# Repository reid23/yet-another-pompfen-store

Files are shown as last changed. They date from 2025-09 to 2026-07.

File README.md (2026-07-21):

# yet-another-pompfen-store

Pompfen engineered for robustness, maintainability, accessibility, and
performance.

> [!IMPORTANT] 
> This content is licensed under [AGPL v3](LICENSE)[^1] because I want
> to encourage sharing within the community.  I hope that I'm never
> going to have to argue about the details with anyone about this. The
> main things I want are:
> 
>  - If you use this in your own work (directly, or even just
>    borrowing some design features), you must also release your work
>    under AGPL v3.  
>  - If you designed your parts in a different cad software, please
>    share the designs in the native format or STEP. I don't think
>    mesh files count as "source".
>  - While not required by the license, attribution would be nice!  
> 
> I am uploading this work for free use (in all senses) because I want
> to see Jugger continue to grow and the equipment to improve. Please
> carry that spirit forward.

## TLDR

- See [order.md](docs/order.md) for information on ordering and poke
  around the configuration options & prices at
  [reid.xz.ax/yaps](reid.xz.ax/yaps) (looks better on a computer than
  on mobile).
- See [code.md](docs/code.md) for information on this codebase and how
  to work with it.
- See [build-your-own.md](docs/build-your-own.md) for how to build
  these yourself!

## Features

Really this section should be after the motivation/project goals bit,
but I know everyone just wants to read the cool feature list first. So
here it is:

- Modularity: the core, blade, buffer, and cover are all separate
  parts which can be repaired or replaced independently.
  - The buffer is a small piece of foam at the back of all blades
    except q-tip. It is squishy, protecting the blade-core interface
    from large forces when a chain wraps and tugs.
  - Removing or installing a blade takes less than a minute.
- Lightweight: these sticks are very light. It's not the bleeding edge
  of lightweight performance, but it's pretty damn good. As a general
  reference, the Q-tip is <250g.
- No more spacers! The foam has a hole inside the same size as the
  core.
- Nylon ripstop blade covers: instead of clear tape, we use nylon
  ripstop fabric. Tears propagate way less, it's lighter, it's
  replaceable, it (imo) looks better, it can be removed and washed,
  and it can be made from a variety of colors for customization.
- Long and Staff blades are interchangeable!
- Choose between a wide (3") or narrow (2.25") staff guard
- EPP reinforcement at the ends of the blades gives Qtip players more
  control and protects the edge of the foam on all weapons.

## OKRs

Here's what this project is trying to do.

When developing these pompfen, I was focused on the following
objectives:
- be inarguably rule compliant
- be safe in normal use and in failure
- be maintainable
- be accessible
- be lightweight
- look good

In order to accomplish this, I developed the following key results:
- The design and manufacturing process must be standardized and
  repeatable to ensure that my goals can be satisfied not just by one
  pompf, but many.
- The design must be modular so that individual components can be
  replaced instead of tearing down the whole pompf every time a small
  fix needs to be made.
- The pompf should withstand many different environments (heat, sun,
  rain, snow, etc).
- The pompf should last through regular usage for at least a year with
  less than $1 and 20 minutes of maintainence over the course of that
  year.
- All safety-critical failures must be visible and ideally not occur
  suddenly (I say 'ideally' because there's only so much you can do if
  the core snaps in half).
- The results of this effort should be made public and free (as in
  free beer *and* as in free speech) for the wider Jugger community to
  use and build upon.
- The pompf should be sold at or below typical US market rates.

Within the bounds of these constraints, I seek to optimize for
weight[^2] and aesthetics.

[^1]: I am aware that this is not very well suited for hardware
    projects (I'm not sure if there even is a good license for
    OpenSCAD projects). But it captures the spirit of what I'm trying
    to do, and I hope that the details never become relevant
    anyway. Please be nice and share your work.

[^2]: technically by weight I mean some strange cost function of the
    inertia tensor that captures what makes a weapon maneuverable. I
    do assume that this function is positive definite though (ie, I do
    not consider the "I like heavy weapons because they make it easier
    to chainbreak/push through an opponent's parry/build
    momentum/etc.).

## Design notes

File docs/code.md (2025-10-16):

## Code Documentation

This document gives an overview of how this design was implemented.

### Setup

There shouldn't be much setup. Just clone the repo. If you don't have [BOSL2](https://github.com/BelfrySCAD/BOSL2) installed, you can just `git submodule init` and `git submodule update` to get it in the repo directory.

You may also need to `chmod +x buildall` before you can run the build script. It references `/usr/bin/python`, so if that doesn't exist, make a symlink (or change the interpreter in `buildall` or run it with python or whatever you'd like)

### Build System

I made a silly little custom build system, since openscad is funny and I couldn't find something that fits my needs.
You'll see comments above modules like this:

```openscad
// @build tip_thread_m_nodfm.stl include_dfm=false
// @build tip_thread_m.stl include_dfm=true
module tip_thread_m(
   // ...,
   include_dfm=true){
    // ...
}
```

This tells the build system to build two stls from this module: one with the parameter `include_dfm` set to `true`, and the other `false`.

To build the .stl files, run the build script:

```bash
./buildall
```

There are a variety of command line arguments. You can see the docs with `./buildall --help`.

This exports all files to the build folder. It also runs the CAM script, which generates some gcode for cutting the EPP. This is not well documented since it was just a one-off I made for myself and my specific setup. If you want to do a similar thing, you should just write your own gcode. It's not hard, and you'll be able to debug it much easier.

If you do want to use mine, you can see the docs like this:
```bash
python epp_cam.py --help
```

Any unknown arguments to `./buildall` are passed to `epp_cam.py`, so you can set the CAM parameters when using the `./buildall` script.

### Assemblies

`assemblies.scad` contains all TLAs (**T**op-**L**evel **A**ssemblies). This is not as helpful as it should be; you still have to go in and highlight or hide things to actually see what's going on, because openscad doesn't have a great way to prevent merging of touching parts.
It maybe helpful to make a section view:

```openscad
difference(){
    long_tla();
    cube(10000, anchor=RIGHT);
}
```

### Parameters

All values are in millimeters. If you have a measurement in inches, there's a convenient variable `INCH` which is defined as `25.4`; please use `INCH` instead of the number to avoid magic numbers.

`params.scad` contains all system-wide parameters. Other parameters fall into two categories:
 - **local parameters** are arguments to modules. They only impact the part generated by that module (not its children).
 - **shared parameters** are variables starting with a `$`, which openscad shares with children. This helps parts that need to fit together share the same parameters. Defaults are defined at the top of the files, and new values can be passed in as keyword arguments to modules.

At some point in the future I hope to integrate this with Customizer, but that's not high on my priority list right now.

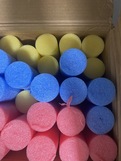
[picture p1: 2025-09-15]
assets/noodle_colors_resized.jpg

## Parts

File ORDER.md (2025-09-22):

## How to Order

You can order a product by sending me a list of SKUs and quantities. Below is the full SKU map.
- Postfix your resulting SKU with the version. This ensures that I'll make compatible components. The current release is always available at [github.com/reid23/yet-another-pompfen-store/releases/latest](https://github.com/reid23/yet-another-pompfen-store/releases/latest).
  - ex: if you order a wide shortstaff guard with cover for version 0.2.1, your final SKU would be `F-GU-SS-COV-v0.2.1`.
- `XXXX` is the cover & foam color options, which are listed [below](#cover--color-options).
- `[SH|LO|QT|ST|SS]` are weapon types. They correspond to short, long, q-tip, staff, and shortstaff, respectively.
- All staff guards will be opaque black for now. If you really want something different let me know, but I don't see a ton of demand for this.

> [!NOTE]
> **UPDATE** I made a little website to help configure this! Go to [reid.xz.ax/yaps](https://reid.xz.ax/yaps) to configure everything and get the price & SKU. The mobile UI is not wonderful, but I have neither the time nor desire to fix it.
> **please still read this file**, since it contains important information and suggestions.

### 1. Full Weapon (`W`)

`CP` ("core provided") is if you'll give me a core or ordered one in the core order and want me to use it. `NC` ("no core provided") is if you want me to provide the core.  

`PO` means "pommel"; `NP` means "no pommel". choose the latter if you want to make your own. You'll need to cut the end of the core to length based on how thick your pommel will be.  

The format is `W-[CP|NC]-[SH|LO|QT|ST[W|N]|SS[W|N]]-[PO|NP]-XXXX`:
- Short: `W-[CP|NC]-SH-[PO|NP]-XXXX`
- Long: `W-[CP|NC]-LO-[PO|NP]-XXXX`
- Q-tip: `W-[CP|NC]-QT-XXXX`
- staff: `W-[CP|NC]-[ST|SS]-[W|N]-[PO|NP]-XXXX`
  - `ST` is full staff, `SS` is shortstaff
  - `W` is wide guard (3"), `N` is narrow guard (2.25")

### 2. Foam (`F`)

This is where you can get blades and guards separately if you want.

Use `COV` if you want a cover or `NC` if you don't (ie, if you're replacing an old bit of foam but the old cover is still fine).

**Important**: if you are reusing a cover, make sure the foam color you request is the same as the one you originally had! Each color of noodle has a slightly different diameter, so the covers are noodle-color-specific.

- Long/Staff (`F-LO-[COV|NC]-XXXX`)
- Short (`F-SH-[COV|NC]-XXXX`)
- Q (`F-QT-[COV|NC]-XXXX`) (only a single blade!)
- Staff Guard (`F-GU-[ST|SS][W|N]-[COV|NC]`) (does not include grip!)
  - `ST` for full staff, `SS` for shortstaff
  - `W` for wide (3"), `N` for narrow (2.25")

### 3. Core (`C`)

Complete cores are cut to length for a weapon and contain all hardware needed for that weapon preinstalled.

The "raw cores" are just what you get from the core order, but immediately! If you need a core now, you can get one, but otherwise i'd recommend waiting for the next core order to get a lower price. These have the 'Reid maintains inventory, fronts cost, and stores cores in his house' fee added.

- Complete (`C-CMP-[SH|LO|QT|ST|SS]`)
- Raw (`C-RAW-[LO|2SH|QT]`)
  - `LO` is 1.35m, for longsword
  - `2SH` is 1.6m, for two shorts.
  - `QT` is 1.9m, for a Q, staff, or shortstaff.

### 4. Parts (`P`)
- Pommel (`P-PO`)
- Blade Hardware Kit (`P-BHK`)
- Staff Guard Hardware (`P-SGH`)
- Staff Grip (`P-SGR-[W|N]`)
  - `W` for wide (3") and `N` for narrow (2.25")

## Pricing

Full weapon costs are the sum of the complete core, foam assemblies, pommel, and grip costs. If you provide a core, there is no core cost, but the appropriate mouting hardware kit costs are added.

Foam Assemblies (Blades/Guards):
- Short: $30 ($21 without cover)
- Long: $40 ($29 without cover)
- Qtip: $28/side ($19 without cover)
- Staff/Shortstaff Guard: $20 ($13 without cover)

Complete Cores (with hardware):
- Short: $21
- Long: $31
- Staff & Shortstaff: $43.5
- Qtip: $44

Raw Cores:
- 1.35m (long): $30.00
- 1.6m (2 shorts): $38.40
- 1.9m (q, staff): $42.50

Mounting hardware kits: 
- $2 per blade
- $1.5 per staff guard

Pommel: $2
Staff grip: $5

A few comments:
- If you have an existing core, I would highly recommend getting a hardware kit and installing it yourself instead of buying a new core. It will cut cost significantly, and the process is very easy. You need superglue, a tape measure, a lighter or heat gun, and some tape (preferrably athletic tape, but any should do).
- If you're replacing an old blade, if the cover is still in good shape, buy a blade without the cover! It's much less labor for me and thus much cheaper for you.
- No tape is applied to the handles by default. If you want it, you need to add it yourself. Everyone has a different opinion on how this should be done, so I'm just going to leave it up to you.

## Cover & Color Options

There are two cover material options:

| Property | 1.1oz Silnylon Ripstop | 1.0 oz MONOLITE Ripstop Nylon Mesh |
| :--- | :--- | :--- |
| **General** | | |
| Waterproof | Yes | No |
| Opaque | dark colors yes, light are more translucent  | No |
| **Dimensions** | | |
| Weight | 1.1 oz | 1.0 oz |
| Thickness | 2.4 thou | 3.9 thou |
| Thread Count (warp/weft) | 200 / 180 per inch | 178 / 178 per inch |
| **Strength (warp/weft)** | | |
| Tear Strength | 13.4 / 10.1 lbf | 1.6 / 3.0 lbf |
| Tensile Strength | 18.9 / 16.2 lbf | 22.3 / 24.8 lbf |

You can see a visual comparison of the two [here](https://www.youtube.com/watch?v=gX634O65S6A). Ignore the first fabric. the second looks like the opaque silnylon but is much weaker because it lacks the silicone coating. the third fabric is the mesh.

There's also Silpoly which looks to have the right specs and has some more colors, but I have not experimented with it yet, so I won't claim that it works well. You can take a look yourself though: https://ripstopbytheroll.com/products/1-1-oz-silpoly

To be entirely honest, the technical details are mostly irrelevant. Both options are similarly strong and robust, and weight basically the same. If anything, the mesh is likely a tiny bit tougher, but rips propagate slightly easier.

I maintain inventory with proper safety stock of black for both of these fabrics. If you want a different color, there will be a $5 additional charge for each new color you'd like (ie, if you order five bright pink pompf it'll still only be $5 extra).

If you would like me to make a cover from a custom fabric, I can do that! Just contact me directly.

The noodle underneath the cover comes in three colors: red, blue, and yellow. They look like this: 

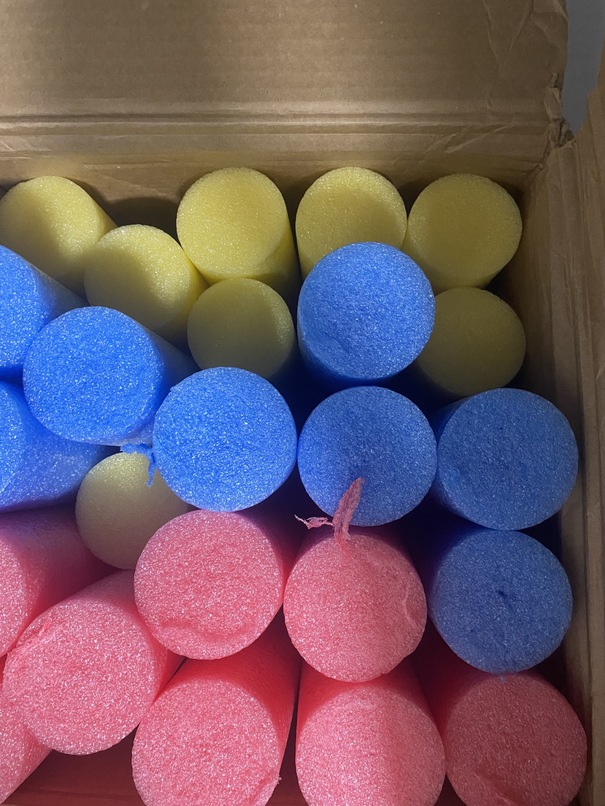
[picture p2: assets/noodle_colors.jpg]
noodle colors


If you go with the opaque Silnylon cover (ie, one of the darker colors of silnylon), you'll basically never see this. At most, it's a tiny accent at the edge of the blade (on everything except qtip, where it isn't visible at all). If you go with the mesh, you can see the color through the cover.

Please let me know what color noodle you'd like by appending an `R`, `B`, `Y`, (red, blue, yellow) or `X` (no preference) to the end of the three-letter ripstop color SKU (see below) you tell me.

The color options in fabrics I've tested are below. Please tell me the SKU of the one you want.

| in stock? | extra fee? | SKU | human readable name  | image |
| --- | --- | --- | --- | ----- |
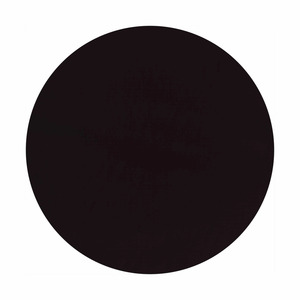
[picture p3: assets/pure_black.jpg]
pure black
| yes | NO  | PBR | pure black |  |
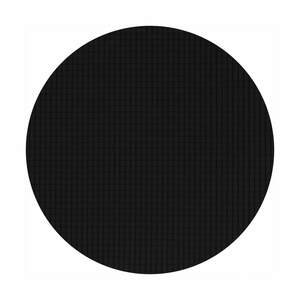
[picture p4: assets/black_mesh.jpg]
black mesh
| yes | NO  | PBM | pure black mesh |  |
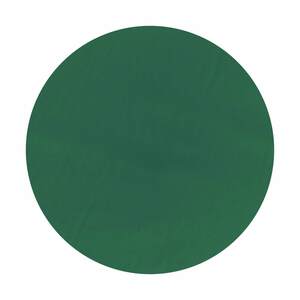
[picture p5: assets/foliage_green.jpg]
foliage green
| yes | yes | FGR | foliage green |  |
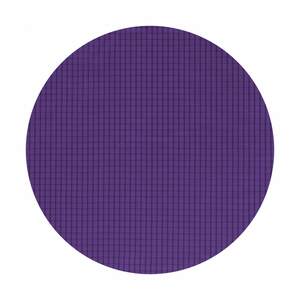
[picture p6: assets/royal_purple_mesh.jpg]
royal purple mesh
| yes | yes | RPM | royal purple mesh |  |
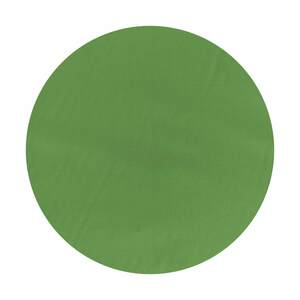
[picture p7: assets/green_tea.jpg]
green tea
| yes | yes | GTR | green tea |  |
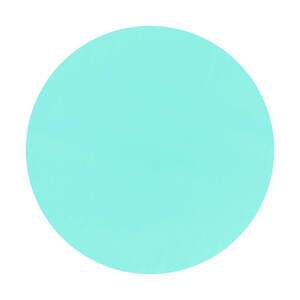
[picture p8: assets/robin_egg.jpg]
robin egg
| yes | yes | RER | robin egg blue |  |
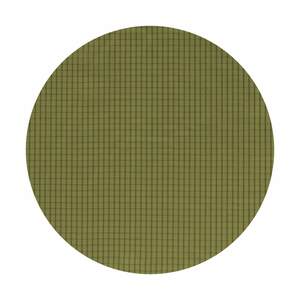
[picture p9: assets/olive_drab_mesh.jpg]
olive drab mesh
| yes | yes | ODM | olive drab mesh |  |
| NO  | yes | RPR | royal purple | royal purple |
| yes | yes | DOR | dark olive | dark olive |
| yes | yes | RTR | real teal | real teal |
| yes | yes | ORM | blaze orange mesh | blaze orange mesh |
| yes | yes | BOR | blaze orange | blaze orange |
| yes | yes | HPR | hot pink | hot pink |
| yes | yes | ODR | olive drab | olive drab |
| yes | yes | PWR | plain white | plain white |
| NO  | yes | CGR | charcoal gray | charcoal gray |
| yes | yes | DOM | dark olive mesh | dark olive mesh |
| yes | yes | MBM | moroccan blue mesh | moroccan blue mesh |
| yes | yes | BOM | burnt orange mesh | burnt orange mesh |
| yes | yes | HGM | hunter green mesh | hunter green mesh |
| yes | yes | WMR | white mesh | white mesh |
| yes | yes | CBR | coyote brown | coyote brown |
| yes | yes | BYR | blaze yellow | blaze yellow |
| yes | yes | CGM | charcoal gray mesh | charcoal gray mesh |

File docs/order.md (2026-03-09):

## How to Order

You can order a product by sending me a list of SKUs and
quantities. Below is the full SKU map.
- Postfix your resulting SKU with the version. This ensures that I'll
  make compatible components. The current release is always available
  at
  [github.com/reid23/yet-another-pompfen-store/releases/latest](https://github.com/reid23/yet-another-pompfen-store/releases/latest).
  - ex: if you order a wide shortstaff guard with cover for version
    0.2.1, your final SKU would be `F-GU-SS-COV-v0.2.1`.
- `XXXX` is the cover & foam color options, which are listed
  [below](#cover--color-options).
- `[SH|LO|QT|ST|SS]` are weapon types. They correspond to short, long,
  q-tip, staff, and shortstaff, respectively.
- All staff guards will be opaque black for now. If you really want
  something different let me know, but I don't see a ton of demand for
  this.

> [!NOTE]
> 
> **UPDATE:** I made a little website to help configure this! Go to
> [reid.xz.ax/yaps](https://reid.xz.ax/yaps) to configure everything
> and get the price & SKU. The mobile UI is not wonderful, but I have
> neither the time nor desire to fix it.  **please still read this
> file**, since it contains important information and suggestions.

### 1. Full Weapon (`W`)

`CP` ("core provided") is if you'll give me a core or ordered one in
the core order and want me to use it. `NC` ("no core provided") is if
you want me to provide the core.  

`PO` means "pommel"; `NP` means "no pommel". choose the latter if you
want to make your own. You'll need to cut the end of the core to
length based on how thick your pommel will be.  

The format is `W-[CP|NC]-[SH|LO|QT|ST[W|N]|SS[W|N]]-[PO|NP]-XXXX`:
- Short: `W-[CP|NC]-SH-[PO|NP]-XXXX`
- Long: `W-[CP|NC]-LO-[PO|NP]-XXXX`
- Q-tip: `W-[CP|NC]-QT-XXXX`
- staff: `W-[CP|NC]-[ST|SS]-[W|N]-[PO|NP]-XXXX`
  - `ST` is full staff, `SS` is shortstaff
  - `W` is wide guard (3"), `N` is narrow guard (2.25")

### 2. Foam (`F`)

This is where you can get blades and guards separately if you want.

Use `COV` if you want a cover or `NC` if you don't (ie, if you're
replacing an old bit of foam but the old cover is still fine).

**Important**: if you are reusing a cover, make sure the foam color
you request is the same as the one you originally had! Each color of
noodle has a slightly different diameter, so the covers are
noodle-color-specific.

- Long/Staff (`F-LO-[COV|NC]-XXXX`)
- Short (`F-SH-[COV|NC]-XXXX`)
- Q (`F-QT-[COV|NC]-XXXX`) (only a single blade!)
- Staff Guard (`F-GU-[ST|SS][W|N]-[COV|NC]`) (does not include grip!)
  - `ST` for full staff, `SS` for shortstaff
  - `W` for wide (3"), `N` for narrow (2.25")

### 3. Core (`C`)

Complete cores are cut to length for a weapon and contain all hardware
needed for that weapon preinstalled.

The "raw cores" are just what you get from the core order, but
immediately! If you need a core now, you can get one, but otherwise
i'd recommend waiting for the next core order to get a lower
price. These have the 'Reid maintains inventory, fronts cost, and
stores cores in his house' fee added.

- Complete (`C-CMP-[SH|LO|QT|ST|SS]`)
- Raw (`C-RAW-[LO|2SH|QT]`)
  - `LO` is 1.35m, for longsword
  - `2SH` is 1.6m, for two shorts.
  - `QT` is 1.9m, for a Q, staff, or shortstaff.

### 4. Parts (`P`)
- Pommel (`P-PO`)
- Blade Hardware Kit (`P-BHK`)
- Staff Guard Hardware (`P-SGH`)
- Staff Grip (`P-SGR-[W|N]`)
  - `W` for wide (3") and `N` for narrow (2.25")

## Pricing

Full weapon costs are the sum of the complete core, foam assemblies,
pommel, and grip costs. If you provide a core, there is no core cost,
but the appropriate mouting hardware kit costs are added.

Foam Assemblies (Blades/Guards):
- Short: $30 ($21 without cover)
- Long: $40 ($29 without cover)
- Qtip: $28/side ($19 without cover)
- Staff/Shortstaff Guard: $20 ($13 without cover)

Complete Cores (with hardware):
- Short: $21
- Long: $31
- Staff & Shortstaff: $43.5
- Qtip: $44

Raw Cores:
- 1.35m (long): $30.00
- 1.6m (2 shorts): $38.40
- 1.9m (q, staff): $42.50

Mounting hardware kits: 
- $2 per blade
- $1.5 per staff guard

Pommel: $2
Staff grip: $5

A few comments:
- If you have an existing core, I would highly recommend getting a
  hardware kit and installing it yourself instead of buying a new
  core. It will cut cost significantly, and the process is very
  easy. You need superglue, a tape measure, a lighter or heat gun, and
  some tape (preferrably athletic tape, but any should do).
- If you're replacing an old blade, if the cover is still in good
  shape, buy a blade without the cover! It's much less labor for me
  and thus much cheaper for you.
- No tape is applied to the handles by default. If you want it, you
  need to add it yourself. Everyone has a different opinion on how
  this should be done, so I'm just going to leave it up to you.

## Cover & Color Options

> [!NOTE]
> 
> I have discontinued the non-mesh cover options, as they would creep
> (stretch) over time and become loose.

I maintain inventory with proper safety stock of black fabric. If you
want a different color, there will be a $5 additional charge (since I
have to order new fabric, pay shipping, and make the covers custom to
order instead of making a bunch ahead of time).

If you would like me to make a cover from a custom fabric, I can do
that! Just contact me directly and we can work something out. I would
recommend that you still keep the ripstop mesh unerneath, since it is
very strong and can serve as the protective layer so you have more
freedom to choose an external decorative layer without worrying about
structural integrity.

The noodle underneath the cover comes in three colors: red, blue, and
yellow. They look like this:

noodle colors

Please let me know what color noodle you'd like by appending an `R`,
`B`, `Y`, (red, blue, yellow) or `X` (no preference) to the end of the
three-letter ripstop color SKU (see below) you tell me.

The color options in fabrics I've tested are below. Please tell me the
SKU of the one you want.

| in stock? | extra fee? | SKU | human readable name  | image |
| --- | --- | --- | --- | ----- |
| yes | NO  | PBM | pure black mesh | black mesh |
| yes | yes | RPM | royal purple mesh | royal purple mesh |
| yes | yes | ODM | olive drab mesh | olive drab mesh |
| yes | yes | ORM | blaze orange mesh | blaze orange mesh |
| yes | yes | DOM | dark olive mesh | dark olive mesh |
| yes | yes | MBM | moroccan blue mesh | moroccan blue mesh |
| yes | yes | BOM | burnt orange mesh | burnt orange mesh |
| yes | yes | HGM | hunter green mesh | hunter green mesh |
| yes | yes | WMR | white mesh | white mesh |
| yes | yes | CGM | charcoal gray mesh | charcoal gray mesh |

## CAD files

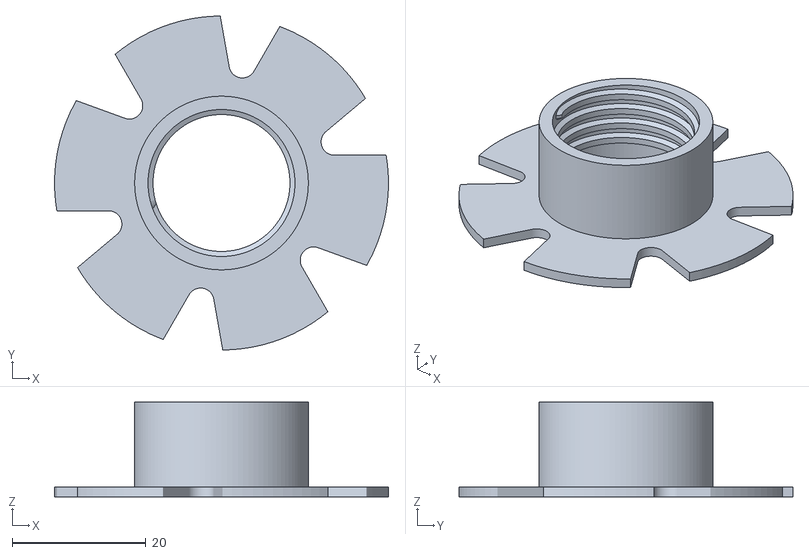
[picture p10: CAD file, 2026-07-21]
build/components/guard_thread_f.stl
50.0 x 50.0 x 14.2

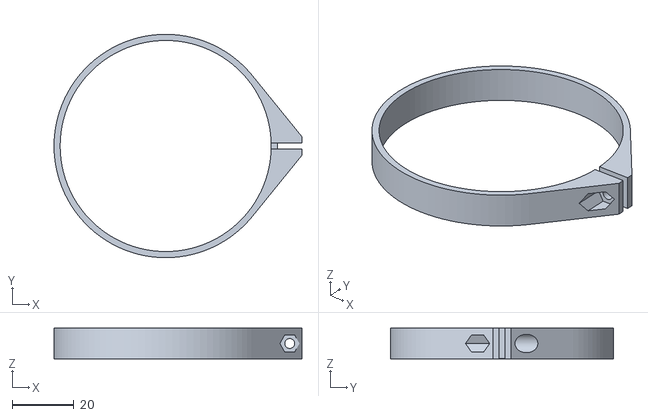
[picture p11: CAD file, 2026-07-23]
build/extras/blade_epp_cutter_outer_clamp.stl
80.6 x 72.6 x 10.0

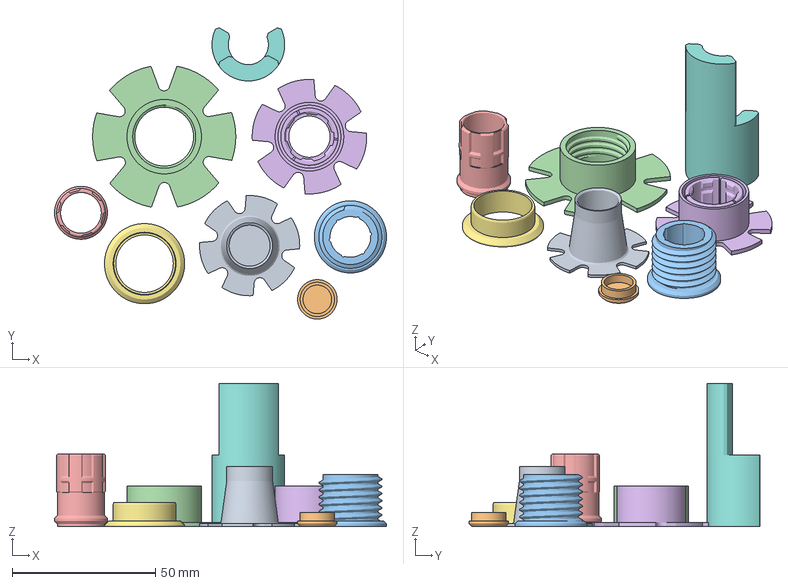
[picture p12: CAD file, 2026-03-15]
slice/pp_all.3mf
115.9 x 101.7 x 50.0 mm
tip_flange.stl
tip_cap.stl
guard_thread_m.stl
guard_thread_f.stl
blade_m.stl
blade_f.stl
collet.stl
staff_guard_spacer.stl

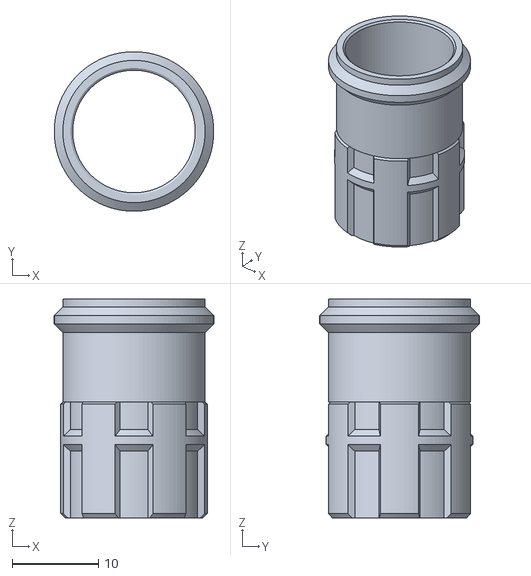
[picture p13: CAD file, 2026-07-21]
build/components/blade_m.stl
18.5 x 18.5 x 25.4

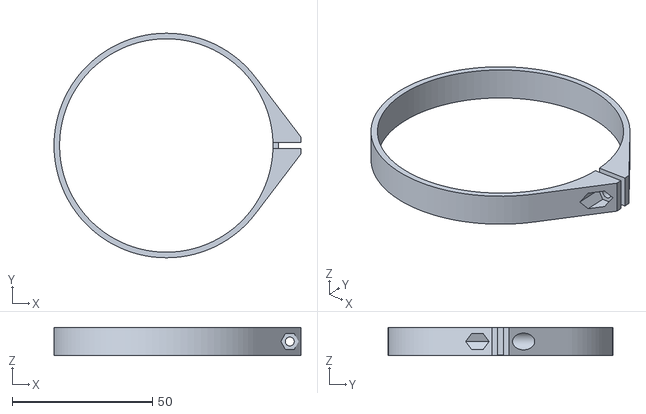
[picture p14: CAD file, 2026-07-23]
build/extras/guard_epp_cutter_outer_clamp.stl
88.2 x 80.2 x 10.0

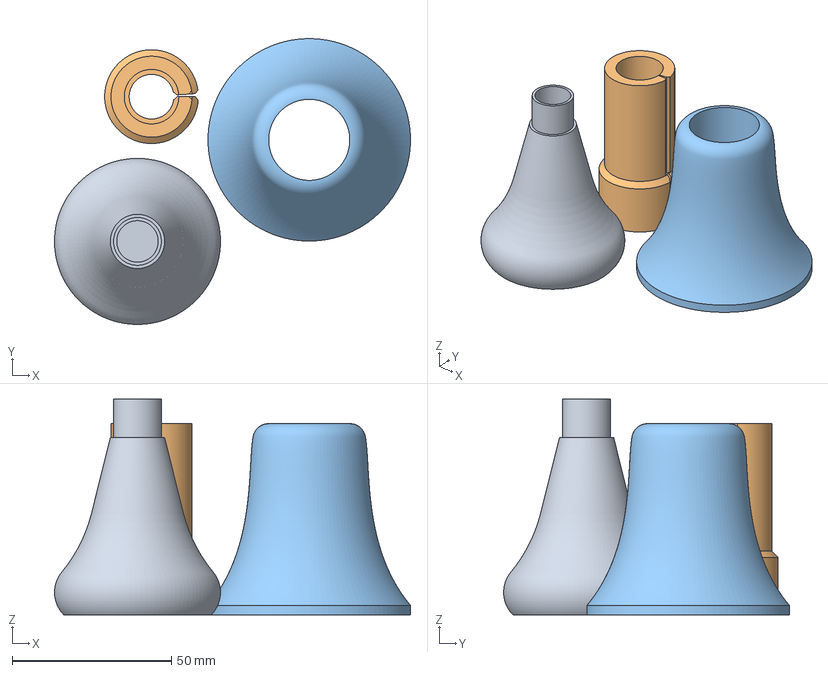
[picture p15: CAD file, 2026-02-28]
slice/flexibles.3mf
111.6 x 89.6 x 67.7 mm
pommel.stl
staff_spacer.stl
staff_grip.stl

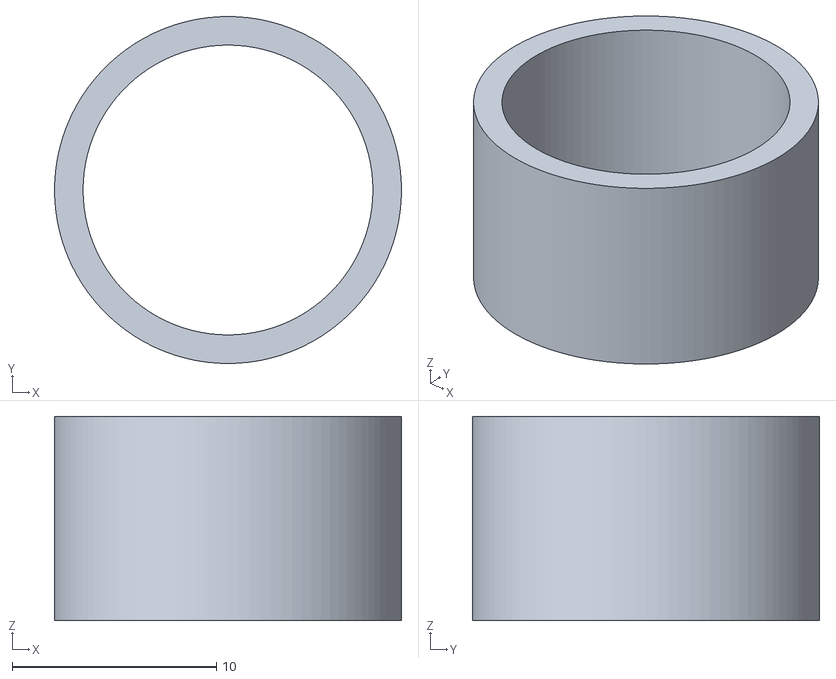
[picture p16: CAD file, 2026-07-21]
build/components/staff_grip_collar.stl
17.0 x 17.0 x 10.0

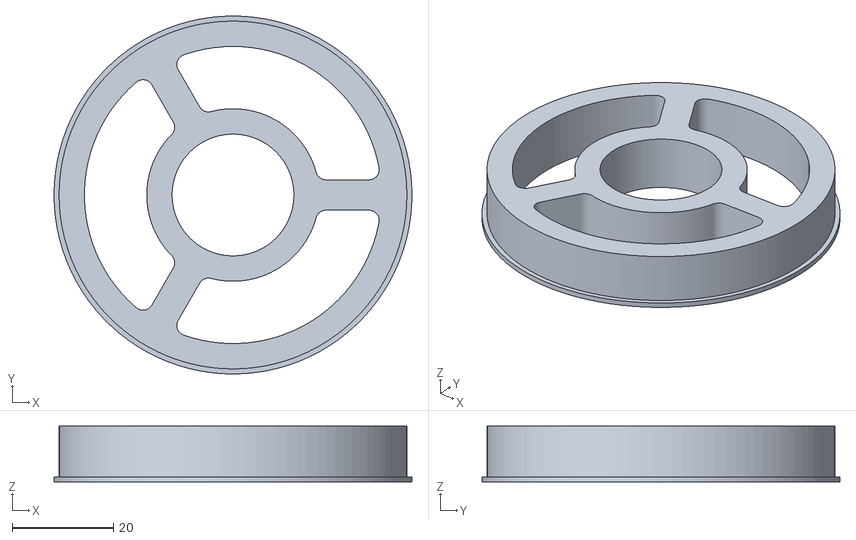
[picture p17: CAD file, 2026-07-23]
build/extras/blade_handside_epp_cutter.stl
70.6 x 70.6 x 11.0

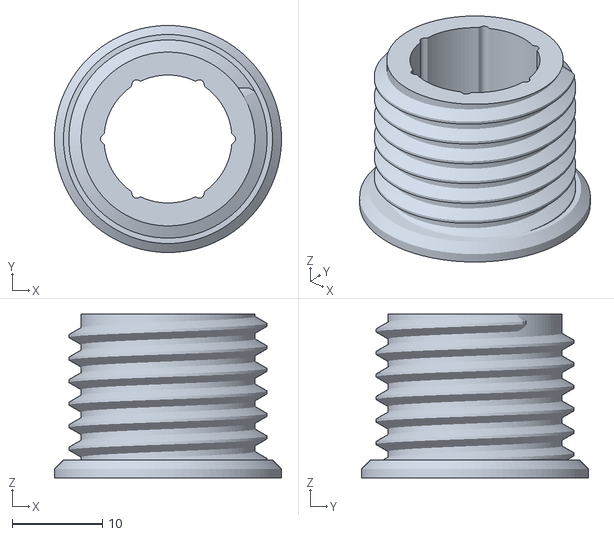
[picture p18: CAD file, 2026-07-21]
build/components/guard_thread_m.stl
25.2 x 25.2 x 18.2

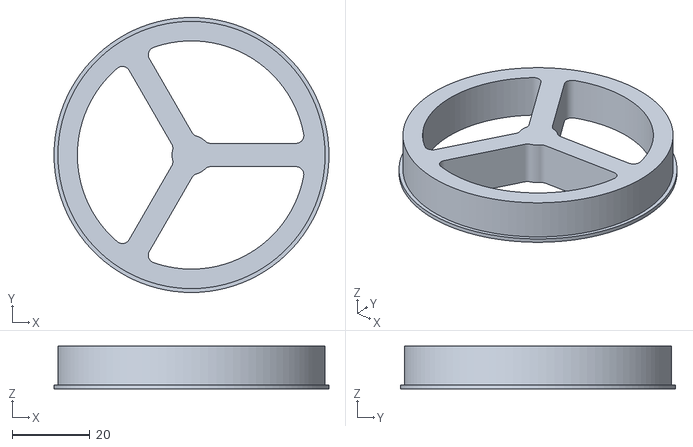
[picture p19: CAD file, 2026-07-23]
build/extras/tip_axial_epp_cutter.stl
70.6 x 70.6 x 11.0

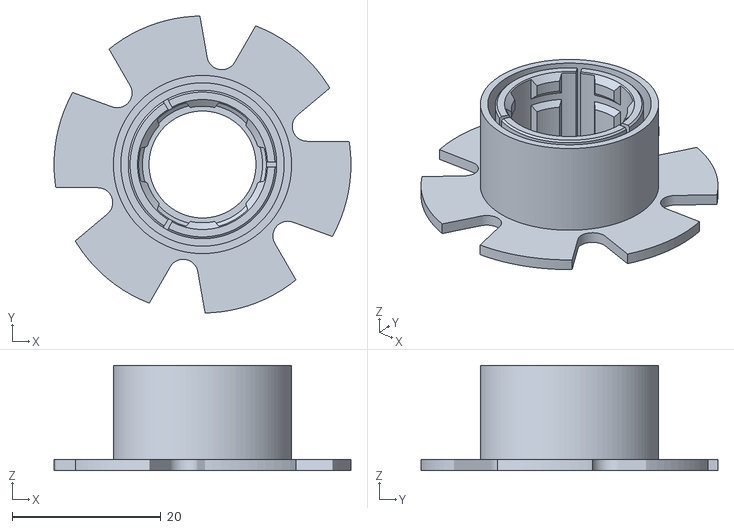
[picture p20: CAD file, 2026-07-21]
build/components/blade_f.stl
40.0 x 40.0 x 14.2

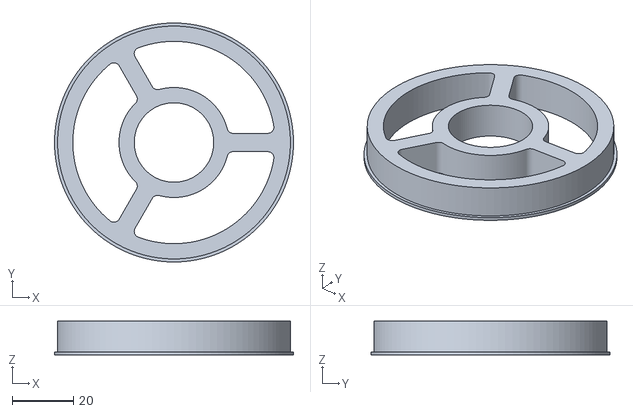
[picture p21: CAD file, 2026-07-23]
build/extras/guard_epp_cutter.stl
78.2 x 78.2 x 11.0

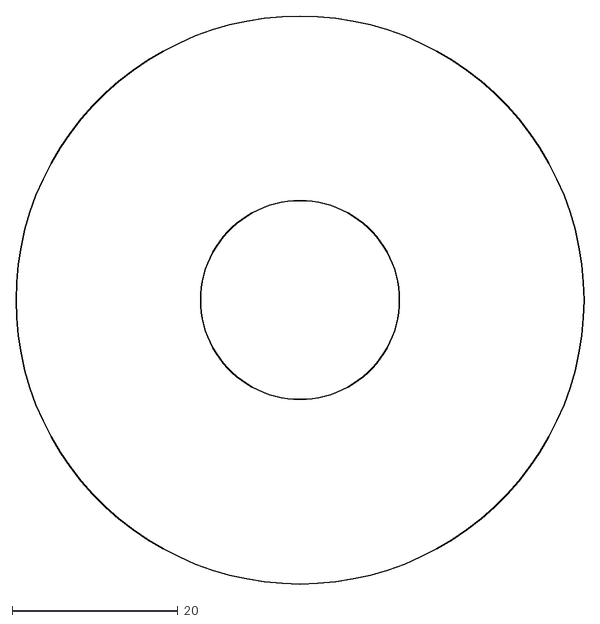
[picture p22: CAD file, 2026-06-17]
build/components/blade_epp_handside.dxf
68.6 x 68.6

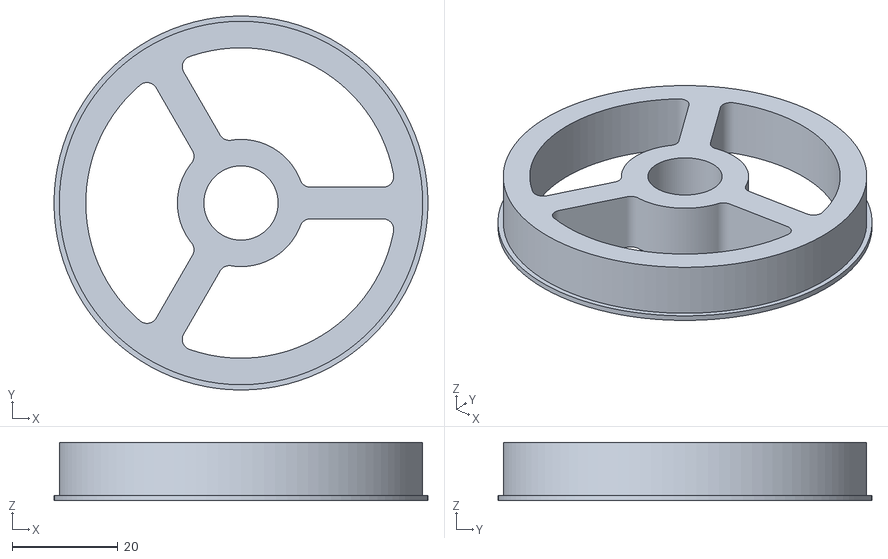
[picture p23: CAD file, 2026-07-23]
build/extras/blade_foamside_epp_cutter.stl
70.6 x 70.6 x 11.0

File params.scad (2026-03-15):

include <BOSL2/std.scad>

$fn = 100;

PRESSFIT = 0.1;
CLEARANCE = 0.2;

//* OVERALL LENGTHS
LONG = 1400;
STAFF = 1800;
SHORTSTAFF = 1700;
QTIP = 2000;
SHORT = 850;
STAFF_REACH = 1100;

//* BLADE LENGTHS
LONG_BLADE = 900;
SHORT_BLADE = 650;
QTIP_BLADE = 600;
GUARD_LEN = 500;
SHORT_GUARD_LEN = 400;

//* COTS PART DIMENSIONS
NOODLE_OD = 2.7*INCH;
GUARD_OD = 3*INCH;
SMALL_GUARD_OD = 2.25*INCH;
EPP_THICKNESS = 0.5*INCH;
COREDIMS = [12, 14];
SHEEP_DIAMETER = (7/16)*INCH;

//* CRITICAL LENGTH PARAMETERS
TIP_THICKNESS = 50;
BUFFER_THICKNESS = 50;
POMMEL_THICKNESS = 10;
STAFF_GRIP_HEIGHT = 60;
STAFF_GRIP_OD = 2.5*INCH;
NARROW_STAFF_GRIP_OD = 2.0*INCH;

ABOVE_CORE_HEIGHT = 2;
CORE_TO_EPP_DIST = 1.5;

POMMEL_OD = 2.05*INCH;
BLADE_EPP_ID = 24;
GUARD_EPP_ID = 26;
TIP_EPP_AXIAL_ID = 0;
TIP_EPP_RADIAL_ID = 19.5;
HEAT_SHRINK_THICKNESS = 0.05;
// magic global vars
// high key i dont like these but
// i think its the best way

$kerf = 2.25;

$guard_pitch = 2.5;
$guard_major_d = 22;
$guard_thread_stop_d = INCH;

$grip_step_size = 2;

// for tip_interface
$pitch=1.5;
$starts=2;
$major_d=COREDIMS[0]-0.4*4-0.3;
$thread_len=4;

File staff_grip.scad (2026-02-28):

include <BOSL2/std.scad>
include <params.scad>
use <utils.scad>

// uses: $grip_step_size
// @build components/staff_grip.stl od=STAFF_GRIP_OD
// @build components/staff_grip_narrow.stl od=NARROW_STAFF_GRIP_OD, w1=40
module staff_grip(
    min_wall_thickness=5,
    od=STAFF_GRIP_OD,
    id=INCH,
    total_length=STAFF_GRIP_HEIGHT,
    start_height=3,
    th1=40,
    th2=10,
    w1=70,
    w2=30,

    anchor=CENTER,
    spin=0,
    orient=UP){
    anchors = [
        named_anchor(name="grip_top", pos=total_length*UP, orient=DOWN),
        named_anchor(name="grip_bottom", pos=CENTER, orient=UP)
    ];
    p0 = [od/2, start_height];
    p1 = [id/2, total_length - min_wall_thickness] + [cos(th2), sin(th2)]*min_wall_thickness;
    v0 = [cos(90+th1), sin(90+th1)]*w1;
    v1 = [cos(90+th2), sin(90+th2)]*w2;
    attachable(anchor, spin, orient, anchors=anchors){
        rotate_extrude() #polygon(concat(
            [[id/2, total_length], 
            [id/2, total_length/3],
            [id/2+$grip_step_size, total_length/3 - $grip_step_size],
            [id/2+$grip_step_size, 0], 
            [od/2, 0]],
            [for(i=[0:0.01:1]) hermite(i, p0, p1, v0, v1)],
            [for(i=[th2:1:90]) [cos(i), sin(i)]*min_wall_thickness + [id/2, total_length-min_wall_thickness]])
        );
        children();
    }
}


// uses: $grip_step_size
// @build components/staff_spacer.stl
module staff_spacer(
    od=INCH,
    slot_angular_size=4,
    height=STAFF_GRIP_HEIGHT,
    shoulder_od=22,
    shoulder_height=2,
    
    anchor=CENTER,
    spin=0,
    orient=UP){
    anchors = [
        named_anchor(name="screw_side_anchor", pos=CENTER, orient=DOWN),
        named_anchor(name="spacer_top", pos=height*UP, orient=UP)
    ];
    id = COREDIMS[1];
    r_c = 1; // rad of chamfer
    attachable(anchor, spin, orient, anchors=anchors){
        difference(){
            union(){
                linear_extrude(height, convexity=20) 
                    _chamfered_slotted_ring(ir = COREDIMS[1]/2, or = od/2, slot_angular_size = slot_angular_size, chamfer_size = r_c);
                linear_extrude(height/3, convexity=20)
                    _chamfered_slotted_ring(ir = COREDIMS[1]/2, or = od/2 + $grip_step_size, slot_angular_size = slot_angular_size, chamfer_size = r_c);
            }
            up(height+0.1){
                cylinder(h=10.1, d=COREDIMS[1] + 3 + PRESSFIT, anchor=TOP);
            }
            up(height/3-$grip_step_size-0.1){
                tube(h=3*$grip_step_size, ir=od/2, or=od/2+2*$grip_step_size+0.1, ichamfer=$grip_step_size+0.1, anchor=BOTTOM);
            }
        }
        children();
    }
}


staff_grip(od=STAFF_GRIP_OD);

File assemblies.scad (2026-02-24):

include <BOSL2/std.scad>
include <params.scad>
use <utils.scad>

use <pommel.scad>
use <staff_grip.scad>
use <tip_interface.scad>
use <guard_interface.scad>
use <blade_interface.scad>

use <core.scad>
use <epp.scad>
use <foam.scad>

$fn = 100;
$include_dfm = false;

module blade(length, buffer=true){
    noodle_length = length
        - (buffer ? BUFFER_THICKNESS : 0)
        - 3*EPP_THICKNESS // 2 on blade side + radial tip epp (axial tip epp is included in TIP_THICKNESS)
        - TIP_THICKNESS;

    tip_flange()
    attach("epp_anchor", "tip_epp_axial_bottom")
    tip_epp_axial(){
        attach("tip_epp_axial_top", "tip_noodle_bottom")
            tip_noodle();
        attach("tip_epp_axial_bottom", "tip_epp_radial_top")
            tip_epp_radial()
                attach("tip_epp_radial_bottom", "core_tip")
                    blade_noodle(noodle_length)
                        attach("hand_side", "blade_epp_foamside_top")
                            blade_epp_foamside()
                                attach("blade_epp_foamside_bottom", "blade_epp_handside_top")
                                    blade_epp_handside(){
                                        if(buffer)
                                            attach("blade_epp_handside_bottom", "buffer_top")
                                                buffer_noodle();
                                        attach("blade_epp_handside_top", "epp_blade_side", inside=true)
                                            blade_f(){
                                                attach("blade_spline_interface", "blade_spline_interface")
                                                    blade_m();
                                                attach("collet_interface", "collet_interface")
                                                    collet();
                                            }
                                    }
    }
}

module staff_guard(od=GUARD_OD, length=GUARD_LEN){
    staff_grip(){
        attach("grip_top", "grip_collar_top")
            guard_grip_collar();
        attach("grip_top", "spacer_top")
            staff_spacer()
                attach("screw_side_anchor", "guard_thread_top")
                    guard_thread_m()// attach("guard_top_thread_reference", "guard_thread_ref_surface")
                        attach("guard_thread_flange_top", "guard_thread_ref_surface")
                            guard_thread_f(){
                                attach("guard_epp_attachment", "epp_bottom")
                                    guard_epp(od);
                                attach("guard_epp_attachment", "guard_foam_top", inside=true)
                                    guard_foam(od, length){
                                        attach("guard_foam_center", "guard_spacer_center", inside=false)
                                            staff_guard_spacer();
                                        attach("guard_foam_center", "guard_spacer_center", inside=true)
                                            staff_guard_spacer();                                        
                                        attach("guard_foam_bottom", "epp_top", inside=true)
                                            guard_epp(od){
                                                attach("epp_bottom", "guard_spacer_bottom")
                                                    staff_guard_spacer();
                                                attach("epp_bottom", "guard_spacer_top", inside=true)
                                                    staff_guard_spacer();
                                            }
                                    }
                                    
                            }

         
    }
}

module long_tla(){
    pommel() attach("core_end", "core_bottom")
        long_core() attach("core_top", "carbon_core_tip")
            tip_cap() attach("effective_core_top", "core_anchor")
                blade(LONG_BLADE);
}

module short_tla(){
    pommel() attach("core_end", "core_bottom")
        short_core() attach("core_top", "carbon_core_tip")
            tip_cap() attach("effective_core_top", "core_anchor")
                blade(SHORT_BLADE);
}

module staff_tla(){
    pommel()
    attach("core_end", "core_bottom")
    staff_core(){
        attach("core_top", "carbon_core_tip")
            tip_cap()
                attach("effective_core_top", "core_anchor")
                    blade(LONG_BLADE);
        attach("reach_limit", "grip_top")
            staff_guard();
    }
}

module short_staff_tla(){
    pommel()
    attach("core_end", "core_bottom")
    short_staff_core(){
        attach("core_top", "carbon_core_tip")
            tip_cap()
                attach("effective_core_top", "core_anchor")
                    blade(LONG_BLADE);
        attach("reach_limit", "grip_top")
            staff_guard(GUARD_OD, SHORT_GUARD_LEN);
    }
}

module qtip_tla(){
    qtip_core(anchor="bottom_tip"){
        attach("core_bottom", "carbon_core_tip", inside=true)
            tip_cap()
                attach("effective_core_top", "core_anchor")
                    blade(QTIP_BLADE, buffer=false);
        attach("core_top", "carbon_core_tip")
            tip_cap()
                attach("effective_core_top", "core_anchor")
                    blade(QTIP_BLADE, buffer=false);
    }

}

$fn=50;

//right(000) long_tla();
difference(){
    right(0) short_tla();
    cube(2000, anchor=RIGHT);
}
//right(200) staff_tla();
//right(300) short_staff_tla();
//right(400) qtip_tla();

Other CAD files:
build/components/guard_epp.dxf
build/extras/tip_radial_epp_cutter.stl
build/components/tip_cap.stl
build/extras/guard_collet.stl
blade_interface.scad
build/components/blade_epp_foamside.dxf
build/components/collet.stl
build/components/pommel.stl
build/components/pommel_modifier.stl
build/components/staff_grip.stl
build/components/staff_grip_narrow.stl
build/components/staff_guard_spacer.stl
build/components/staff_spacer.stl
build/components/tip_epp_axial.dxf
build/components/tip_epp_radial.dxf
build/components/tip_flange.stl
build/extras/blade_foamside_collet.stl
build/extras/blade_handside_collet.stl
build/extras/epp_support_blade.stl
build/extras/epp_support_narrow_guard.stl
build/extras/epp_support_wide_guard.stl
build/extras/fatigue_jig_bumper.stl
build/extras/fatigue_jig_encoder_mount.stl
build/extras/fatigue_jig_sample_mount.stl
build/extras/fatigue_jig_strain_guage_mount.stl
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

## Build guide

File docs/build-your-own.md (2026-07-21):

# Building Your Own

My intent is to sell these, but that doesn't mean you can't make your
own! I caution that these were designed to be easy to make at a
larger scale, so the time and material cost may be much higher for
you.

> [!IMPORTANT] Please read this entire document before deciding to
> build your own. If you get halfway through and realize that this is
> too complicated or requires tools you don't have, it will not be
> very fun.

## 3D printed parts

There are rigid and flexible parts. I recommend printing the rigid
parts in polypropylene, because it is very lightweight, very
isotropic, quite soft, and yields and necks before breaking (instead
of just shattering like PLA). I'd highly recommend getting some
Magigoo PP to help with bed adhesion; PP is very hard to stick to
anything.  The flexible parts are less material dependent. The
provided slicing settings assume a shore hardness of ~83A, though 85A
probably will work too.

Use the `flexibles.3mf` and `pp_all.3mf` files from the `slice`
folder. They were exported with PrusaSlicer; I'm not sure how well
that plays with other slicers. Hide/show and duplicate components
based on what you need.

## Foam

There are three types of foam:
- solid core noodle, for the blade
- 1/2", 1.3lb/cubic foot EPP sheet
- 3"x1" pipe insulation or 2.25" hollow noodle for the guard
  (depending on how big you want your guard)

### Solid Core Noodle

For the solid core noodle, for each blade, you'll need:
- one tip, which is just a 37.3mm thick piece of solid noodle
- one blade, a piece of cored solid noodle of the length specified in
  the table below.

> [!IMPORTANT] 
> 
> As of v0.3.0, the heat shrink reinforcement of the internal diameter
> is **required**. It ensures that there is no axial stretching, which
> is needed in place of the tip thread.

| pompf | nominal blade length | recommended cut length |
|---|---|---|
| long  | 821.9 | 830 |
| short | 571.9 | 580 |
| qtip  | 511.9 | 520 |

This produces a blade that is one centimeter oversized for longs and
qtips and a blade that is precisely correctly sized for qtips. This is
because the active constraint on blade length for qtips is a maximum,
while for the others, it is a minimium. The extra length added to get
the recommended cut length is to add preload during the glueup; the
final blade length will be the correct nominal length.

To create the cored noodle, you need to cut a hole of the appropriate
size down the center of the solid core noodle. I have a jig for that
[here](https://www.printables.com/model/1233976-pompf-coring-jig/files). You
heat up the brass tube with a heat gun (don't use a flame; it makes
the foam stick to the tube) and push it through the noodle.

#### ID Reinforcement

To reinforce the internal diameter of the foam and prevent it from
cracking, we create a tube out of heat shrink film tubing and glue the
blade to it. I use Uline `S-23533` tubing.

First, prepare a mandrel. This may take a bit.

1. Take a spare core and glue on a cap (like
`build/components/tip_cap.stl`).
2. Apply a single layer of clear tape to the core, ensuring everything
   is perfectly smooth and there are no bubbles. The tape should be
   aligned axially (the long way, not in short little loops) and
   should start 3cm from the tip with the cap and extend down at least
   5cm longer than the blade you are trying to make.

Then, cut an oversize length of heat shrink tubing, put it over the
mandrel, and shrink it with a heat gun. Ensure that:

- it does not have any wringles oriented perpendicular to the core;
axially aligned wrinkles should be avoided if possible but are
okay.[^1]
- there is at least a little bit of heat shrink extending past the tip
  of the core to prevent the tube from sliding down the core if it
  were pulled
- the section of tubing above the core pinches all the way closed (you
  can help it by twisting it while it's heated) 

Finally, trim the section of the tubing that is above the core so it's
just long enough to pinch closed all the way and isn't sticking out
too much past the diameter of the core. Then once the tubing is cool,
remove it from the mandrel.

### EPP

For the EPP sheet, you'll need to cut circles. I do this by strapping
a hot knife foam cutter to my 3D printer and running the gcodes in the
`build` folder. Workholding is done by double-sided taping EPP
rectangles to the `epp_support_[type]` part. If those parts are too
big for your printer, you can set the `nrows` and `ncols` parameters
by editing the `// @build` comments (see [the build system
docs](code.md#build-system) for more info on how this works) above the
`epp_support` module and then rebuilding.

There are pre-generated gcode files for this in the `build/gcode`
folder. Each blade requires 4 pieces of EPP; two on the tip side and
two on the hand side. Each guard requires two
pieces. `blade_hand.gcode` and `blade_tip.gcode` each cut three pairs
of EPP pieces for their respective sides of the
blade. `narrow_guards.gcode` and `wide_guards.gcode` each cut three
pairs of EPP (enough for three guards) each.

Before you run those, though, you may need to tune the kerf of your
hot knife. Cut through the foam at 100mm/min and measure the kerf in
millimeters. Divide that by two to get the radius of the cut.

First, update the `epp_support`. Pass `$kerf=<your_kerf_radius>` in
the `// @build` comments above the `epp_support` module and then
rebuild.  Then, from the root directory of this repo, run:

```bash
python epp_cam.py --kerf your_kerf_radius_here
```

This will generate new gcode files that will cut the shapes accurately
for you.

Be sure to do these in this order, since rebuilding with `./buildall`
overwrites the results of running `epp_cam.py`.

If you want to cut many pieces of EPP at once, you can use the
`-z`/`--zclear` parameters to set the travel height. For more
information on the arguments to `epp_cam.py`, use the standard help
flag:

```bash
python epp_cam.py --help
```

### Staff Guard

There isn't much to this one. Just take your selected material and cut
it to length. For a full length staff, that's 412.6mm, and 100mm less
for a shortstaff.

## Covers

I'd save the covers for last, after you've assembled everything. That
way it's easier to test the fit. The dimensions of the cover change
based on the precise diameter of your noodle, so you'll have to tune
it at least once for each cover type you make.

For blade covers, the procedure is:
1. cut a rectangle big enough for the cover
2. hem one short side to create a loop for the wire to go through
3. fold it in half the long way and pin/tape it somehow, making sure
   the hem on the side is on the outside
4. mark the distance from the folded edge that you plan to sew.
5. sew it! I use a Serger style machine for this part because it's
   fast and I have access to one, but if you don't, a normal machine
   works fine. Just be sure to add multiple stitches so it doesn't
   fray and fall apart super fast.
6. test fit on your stick and measure & mark where you want to sew
   across the top
7. turn it back inside out and sew a straight line across the top
8. sew the two corners together and trim any excess fabric
9. use a lighter to clean up any wispies and seal in the edges of the
   ripstop, especially around the hem you made in step 2.
10. Cut a small hole in the loop of the hem where you can insert the wire.

For guard covers, the procedure is the exact same, except that you
should hem both short sides and you don't need to close off the tip.

## Assembly

### Cores

Cut the cores to the appropriate length. The measurements I use are:
- short: 838mm
- long: 1388mm
- Staff: 1788mm (100-150mm shorter for shortstaff)
- Qtip: 1896mm

In reality you often want to cut them a little shorter to make sure
you're safely within the legal length. How much you take off is up to
you.

Then, measure out where the hardware is supposed to go on the core,
ensuring you have the clearances in the right direction to be
legal. (I'll write up measurements with clearance directions specified
here eventually but I believe in you to figure it out).  Then,
everywhere you have to attach a (non-removable) printed part, sand the
core a little bit to scratch the surface, clean it, and then superglue
the part on. Try to put a little glue on the edges of the part as well
to provide a more mechanical means of locking the part in place.

For `blade_m`, make sure the (more) blank part is on the hand side of the
blade. Apply some adhesive heat shrink tubing (the kind for
electronics) over the blank part to help hold it in place.

For staffs, use small bits of heat shrink to create stops on the core
to hold the four `staff_guard_spacer`s in place.

### Blades

#### Tip Assembly

The final tip assembly should look like this:

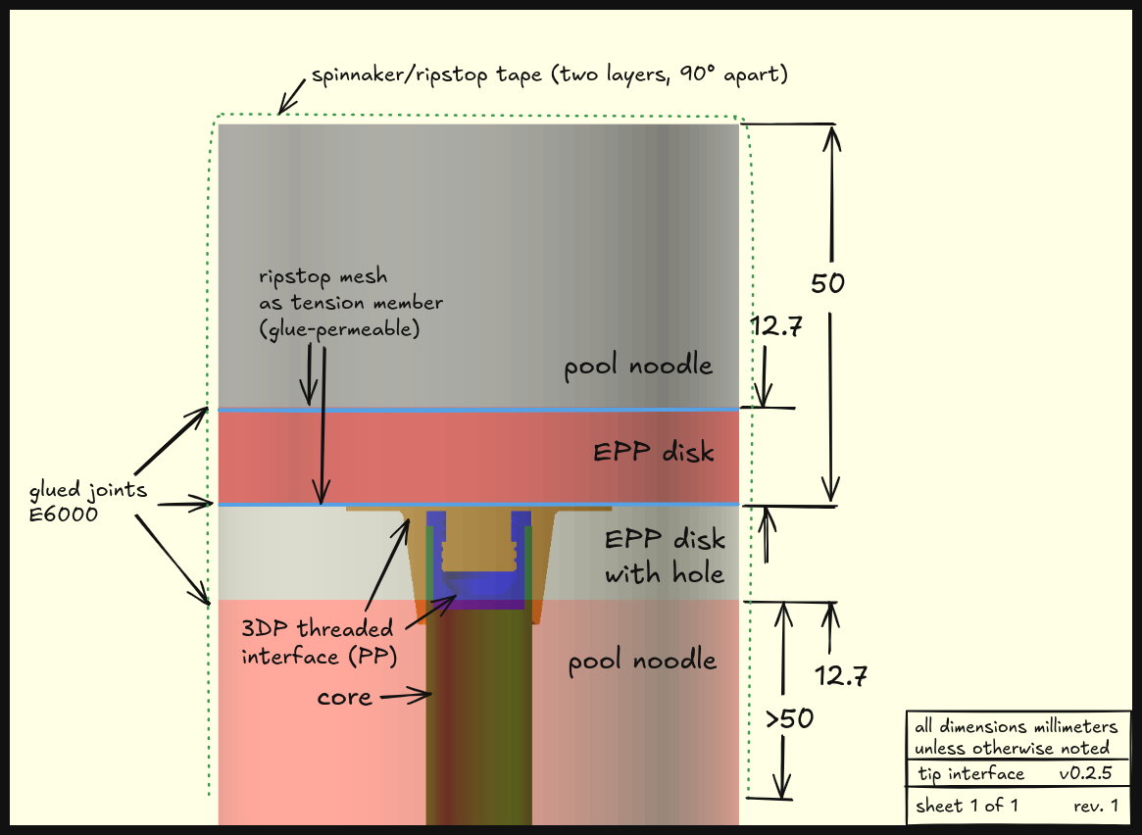
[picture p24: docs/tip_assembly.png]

(yes the printed parts are slightly different; don't worry about it)

To build this:

1. cut the tip pool noodle to length and cut out the EPP disks
2. cut out two bits of ripstop mesh larger than the diameter of the tip
3. apply glue around the entire outside of `tip_flange` and push it into the
   disk that has a hole.
4. apply glue all over one side of the solid EPP disk and push it onto
   the flange side of the existing assembly with one piece of ripstop
   mesh between them
5. do the same thing for the other side of the solid EPP disk: apply
   glue, apply ripstop, and press the tip noodle on.
6. clamp it together! To ensure everything is clamped properly, put
   another piece of EPP with a hole in it on the bottom side,
   protected by a piece of wax paper with a hole just large enough for
   the `tip_flange`'s extending tube part to pass through.

Leave this clamped to cure for at least 24 hours.

#### Hand Side Assembly

The hand side assembly is simpler so I don't have a diagram. 

1. Apply glue all around the outside of the `blade_f` and insert it into the EPP disk with the larger hole
2. Apply glue evenly around the flanged side of the assembly and press the other EPP disk on
3. Place this assembly on a core (to ensure all the holes stay aligned) and clamp it together.

Leave this clamped to cure for at least 24 hours.

#### Gluing!

This is the *final glueup of the entire process*. You should have both
EPP assemblies ready and a core with all necessary hardware installed
before beginning.

Just like with the EPP assemblies, I've used E6000 and seen good
results, but I'm sure there's plenty of other adhesives that would
work okay.

First, place the hand side EPP assembly on the core and secure it with
the collet.  Then, place the tube on the core and trim the bottom
until it is the right length to seat against the printed part inside
the EPP assembly and on the tip at the same time. This means that the
tube should go *inside* one of the two slices of EPP. It is vital
that you cut the tube to the right length to **within +0/-5mm**.

Once it is cut to the right length, apply glue to the very bottom of
the tube and slide it all the way onto the core. This should glue the
tube to the internal face of one slice of the hand side EPP assembly.

Next, apply glue in two places:
1. around the tube, ensuring even glue distribution around the radius
   (even distribution along the core doesn't matter). This is the glue
   that will end up holding the bottom half of the blade to the tube.
2. inside the cored noodle, from both sides, but mostly from the side
   you're going to put the core into. This is the glue that will end
   up holding the top half of the blade to the tube.
   
Then, gently push the cored noodle onto the core around the tube. Glue
will gradually get sucked into the joint on both sides. If either side
seems to run out, replenish it.

When you are nearing the end, apply glue to the entire face of the
hand side EPP assembly to glue it to the noodle. Pulling on only the
bottom half of the noodle (the hand side half), close the gap just barely.

Then, on the tip side, keep pushing the noodle down until there is up
to 5-10mm of exposed core and tube. Then:
1. cover that section of tube as well as the top face of the noodle in
   glue.
2. cut off the very top of the tubing so that it does not extend
   higher than the top of the core cap. You can use a knife to cut
   around the circle. Be careful not to get any glue above the cut.
3. Put the tip on, being careful not to crease the tube at all. Ensure
   the tip goes *all the way on*.

#### Taping

> [!IMPORTANT]
> **On the Use of Tape**  
> To ensure the strength and longevity of taped joints, make sure that you:
> - minimize touching the adhesive with anything
> - minimize the amount of dust in the air (ie, don't do this in a woodshop)
> - apply firm pressure on every piece of tape to ensure the adhesive 
>   activates and forms a good bond
> - ensure target surfaces are clean, especially from any sorts of oils.
> - ensure that tape is loaded fairly evenly across its width, especially
>   since both athletic and spinnaker tape do not provide much shear strength.
> - minimize any wrinkles and sharp exposed tape corners; these are things
>   that can catch on things and reduce effective adhesive area.

Now, taping!  It's rather hard to clamp this glueup, so instead we
tape it. Cut two pieces of spinnaker tape, each 250-300mm long. Apply
them over the top of the tip at a right angle to each other, ensuring
there is significant preload holding the tip down and pulling the
blade foam up.

Then, repeat the same procedure for the hand side. You will need to
cut a circular hole in the middle of the tape to make room for the
collet. If you're building a Q-tip, I recommend doing each side
separately so that you can still put the tape over the opposite end of
the core. Likewise, don't put a pommel or staff guard on the end of
the core so that you can put this tape on.[^2]

#### Curing

Wait at least 24 hours for everything to cure before even thinking
about removing it from the core.

### Staff Guards

First, assemble one `guard_epp` and the `guard_thread_f`:
1. put them together
2. wrap them in two loops of athletic tape, the second loop
   perpendicular to the first.
3. use flush cutters to cut holes in the tape, with the same caution
   as for `blade_epp` and `blade_f`. Particularly ensure that on the
   flange side, the tape does not hang over the hole at all.

Now, put the `guard_epp` and `guard_thread_f` assembly on the guard
foam (the insulation or hollow noodle). Make sure the flange of
`guard_thread_f` is sandwiched between the EPP and guard foam. Use a
hoop of athletic tape to attach the two.

Then, use another loop of athletic tape to attach the second
`guard_epp` to the other end of the guard foam.

Finally, put the guard cover over the guard and use one piece of wire
on each side to affix it.

### Final Assembly

First, put the pommel on, if the stick you're building has one. Secure
it with two pieces of heat shrink: one just over the small shoulder of
the pommel and another on top of that, extending further up onto the
pommel.

Then, if you're building a staff:

1. put the four `staff_guard_spacer`s on between the heat shrink collars. 
2. put the guard foam on and thread it down until it is
   tightened. Don't put more than like 0.5 Nm into tightening it.
3. put the `staff_spacer` over the core in front of the guard foam.
4. put the `staff_grip` over the spacer.

[^1]: this is because we rely on this tube for some axial strength
    during installation, so horizontal wrinkles essentially pre-buckle
    it for us and can cause installation issues.

[^2]: lwk this is bad form because I should warn about this
    beforehand, but if you got this far without reading the entire
    document first, maybe this will serve as a good lesson.

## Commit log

2025-07-30 added epp cam and old gcodes
    [splined.scad, testing.scad]
2025-08-01 made threaded.scad and added tip stuff
    [foam.scad, threaded.scad]
2025-08-02 new tip thread and more assemblies!
    [assemblies.scad, core.scad, epp.scad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]
2025-08-04 made long assembly. it's off by a little but is otherwise fine
    [assemblies.scad, core.scad, epp.scad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]
2025-08-08 new threads and fixed staff grip length and added staff spacer
    [assemblies.scad, flexibles.scad, threaded.scad]
2025-08-11 added build script and folder with outputs as well as BOSL2 as a submodule so people don't have dependency issues.
    [assemblies.scad, blade_m.stl, collet.stl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]
2025-08-12 revamped build script in python to allow multiple file exports with different args from a single module
    [blade_f.stl, blade_m.stl, collet.stl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]
2025-08-13 staff grip updates
    [flexibles.scad, threaded.scad]
2025-08-19 updated readme with license disclaimer and assembly info
2025-08-20 added guard male threads
    [assemblies.scad, blade_f.stl, blade_m.stl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]
2025-08-20 updates for zero width pin
    [flexibles.scad, params.scad, splined.scad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]
2025-08-21 added staff guard parts and the remaining assemblies. Shortstaff is still in progress because I don't have good numbers on the ideal length. also updated the readme to reflect these changes
    [assemblies.scad, blade_f.stl, blade_m.stl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]
2025-08-27 added initial slicing settings with .3mf files, and added modifier volume for pommel
    [blade_f.stl, blade_m.stl, collet.stl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]
2025-09-15 fixed the assemblies and put back the threaded stuff i deleted
    [assemblies.scad, blade_f.stl, blade_m.stl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]
2025-09-17 new staff grip that doesn't slide, fixed guard thread parts to only have one flange, and finalized tip thread geometry
    [assemblies.scad, blade_f.stl, blade_m.stl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]
2025-09-19 refactored everything to be better organized and updated the order document to say that light colored silnylon is not entirely opaque
    [assemblies.scad, blade_interface.scad, core.scad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]
2025-09-19 made staff grip assy printable without supports and increased length and diameter of grip. updated order doc with complete sku system.
    [assemblies.scad, blade_f.stl, blade_m.stl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]
2025-09-22 second staff grip, new cam, slight updates to order and readme for release
    [blade_f.stl, blade_m.stl, collet.stl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]
2025-09-28 new staff guard and some fixes and refactoring
    [assemblies.scad, blade_f.stl, blade_interface.scad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]
2025-09-30 more docs in progress, need to also update the 3mf files
    [pp_all.3mf]
2025-10-03 some small updates and new slicing files as manufacturing begins
    [blade_f.stl, blade_interface.scad, blade_m.stl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]
2025-10-16 adjustments for v0.2.4, pre-juggerlandia
    [assemblies.scad, blade_f.stl, blade_m.stl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]
2025-10-16 updated build script to have better docs and features. Also updated pommel to have slightly smaller ID as Thalia suggested
    [blade_f.stl, blade_m.stl, collet.stl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]
2025-12-14 added second EPP bit on blade side, added uv files for including openscad_docsgen which ill eventually write real docs for, and refactored the blade assemblies to be one parameterized function instea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
    [assemblies.scad, blade_interface.scad, epp.scad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]
2025-12-19 refactored to have `use` everywhere instead of `include` so i can have each file build parts
    [assemblies.scad, epp_support.scad, guard_interface.scad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]
2025-12-21 four pieces of EPP per blade now, better cam export
    [blade_f.stl, blade_m.stl, collet.stl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]
2025-12-27 new slots for glue method to improve torque transfer
    [blade_f.stl, blade_interface.scad, blade_m.stl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]
2026-01-10 added stock origin argument properly bc 3d printers arent cnc machines
2026-01-27 added fatigue testing jig parts and organized the build folder a little
    [blade_f.stl, blade_interface.scad, blade_m.stl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]
2026-02-08 fatigue jig stuff, pommel heat shrink extension, and blade m mold
    [blade_f.stl, blade_interface.scad, blade_m.stl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]
2026-02-08 removed the mold since i think casting is a lost cause (or would require way too much r&d)
    [blade_interface.scad]
2026-02-08 increased angle of pommel modifier to decrease ability of pommel to break off at a flat layer
    [pommel.scad]
2026-02-24 updated slice and build files but docs and assemblies are still iffy
    [assemblies.scad, blade_f.stl, blade_interface.scad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]
2026-03-09 updated the docs with the new glueup procedure
    [blade_interface.scad, blade_m.stl, pp_all.3mf]
2026-03-10 rebuilt and removed old parts
    [blade_f.stl, blade_m.stl, collet.stl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]
2026-03-11 updated pp slice file
    [pp_all.3mf]
2026-03-15 new guard_thread_f to pass over the new blade_m, and update build script to display modules that had echo output in a more logical way
    [blade_f.stl, blade_m.stl, collet.stl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]
2026-03-15 updated slice file to match new build output
    [pp_all.3mf]
2026-06-17 added dxf export capacity to build system and built epp dxf files
    [blade_epp_foamside.dxf, blade_epp_handside.dxf, blade_f.stl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]
2026-07-21 added new EPP cutting jig
    [blade_f.stl, blade_foamside_collet.stl, blade_foamside_epp_cutter.stl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]
2026-07-23 oops, fix build bug
    [blade_epp_cutter_outer_clamp.stl, blade_foamside_epp_cutter.stl, blade_handside_epp_cutter.stl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]
2026-07-23 made outer_clamp actually printable
    [blade_epp_cutter_outer_clamp.stl, guard_epp_cutter_outer_clamp.stl, holesaw.scad]
